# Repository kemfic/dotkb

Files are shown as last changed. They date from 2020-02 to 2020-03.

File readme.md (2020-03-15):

dotkb
---

keyboards, nothing too special. the **micro** is the only one i made so far

the micro
---
<p float='left'>
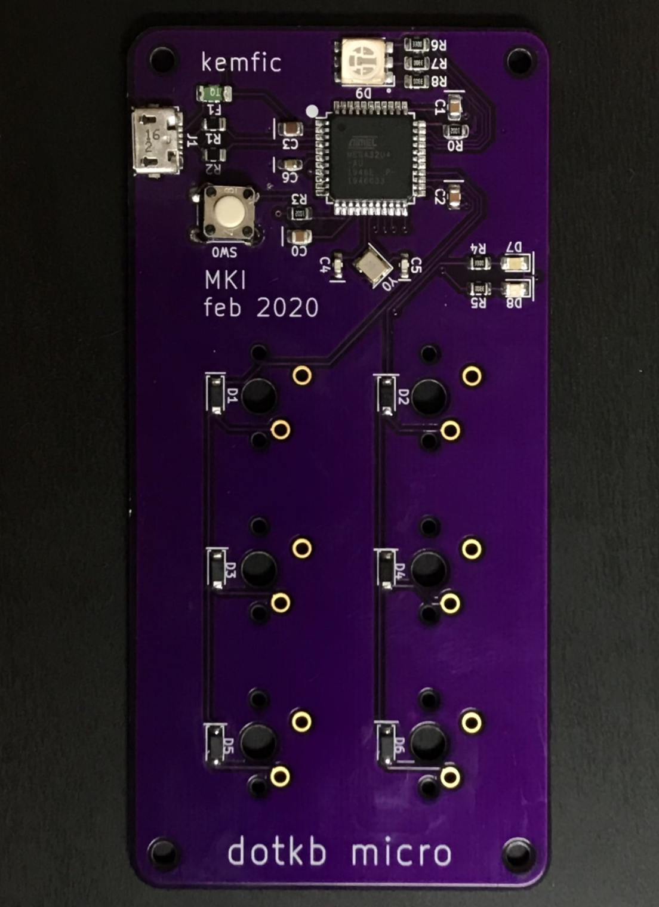
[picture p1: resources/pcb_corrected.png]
    
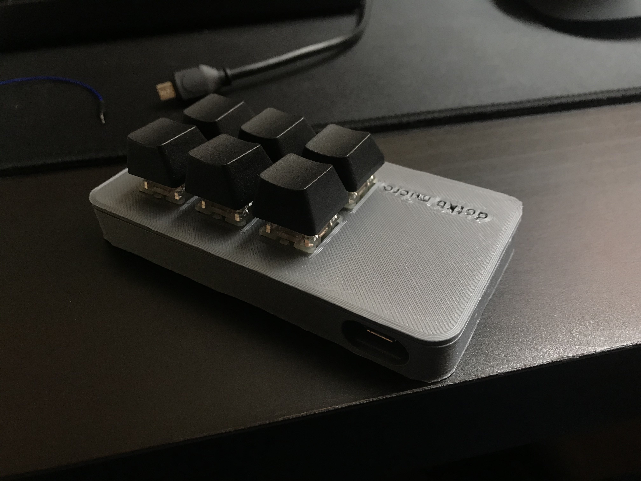
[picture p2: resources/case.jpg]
    
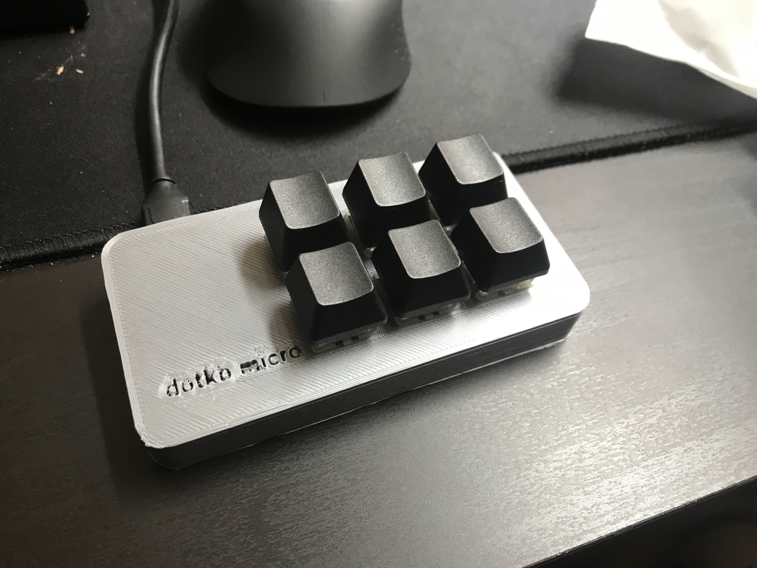
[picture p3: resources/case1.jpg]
    
</p>

features
---
 - MEAT CHECK

LICENSE
---
MIT licensed. don't sue me

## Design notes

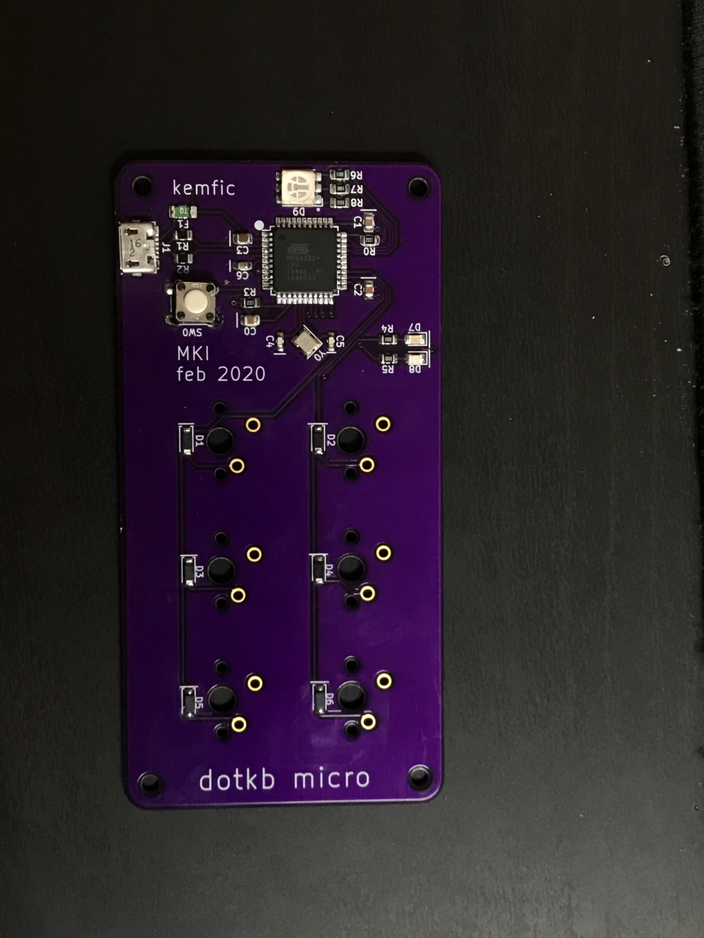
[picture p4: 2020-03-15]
resources/pcb.jpg

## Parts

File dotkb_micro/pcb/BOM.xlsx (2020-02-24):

Item | Footprint | Value | Qty | Unit Price | Total Price | Source | Part No. | Notes
Atmega32u4 | TQFP |  | 1 | 4 | 4 | Mouser | 556-ATMEGA32U4-AU
SMD Capacitor | 0805 / 2012 | 0.1uF | 3 | 0.24 | 0.72 | Mouser | 80-C0805C104K9RAUTO
SMD Capacitor | 0805 / 2012 | 10uF | 1 | 0.82 | 0.82 | Mouser | 80-C0805X106K9RAUTO
SMD Capacitor | 0603 / 1608 | 22pF | 2 | 0.26 | 0.52 | Mouser | 581-06036A220JAT2A
SMD Capacitor | 0603 / 1608 | 1uF | 1 | 0.17 | 0.17 | Mouser | 581-06036D105K
SMD Diode | D-SOD-123 |  | 7 | 0.46 | 3.22 | Mouser | 755-RRD07MM4STR
SMD LED | 0805 / 2012 | Yellow | 1 | 0.28 | 0.28 | Mouser | 720-LYR976-PS-36
SMD LED | 0805 / 2012 | Green | 1 | 0.27 | 0.27 | Mouser | 720-LGR971-KN-1
SMD RGB LED | 5050-6 | RGB | 1 | 4.95 | 4.95 | Mouser | 485-619 | Adafruit
SMD Fuse | 1206 / 3216 | 5v 500mA | 1 | 0.3 | 0.3 | Mouser | 504-PTS12066V050
Molex SMD Micro-B USB Female Connector | Micro B |  | 1 | 1.05 | 1.05 | Digi-Key | WM17141CT-ND | Molex
SMD Resistor | 0805 / 2012 | 22 Ohm | 2 | 0.25 | 0.5 | Mouser | 71-RCS080522R0FKEA
SMD Resistor | 0805 / 2012 | 10k | 2 | 0.1 | 0.2 | Mouser | 71-CRCW080510K0FKEAC
SMD Resistor | 0805 / 2012 | 330 Ohm | 5 | 0.1 | 0.5 | Mouser | 71-CRCW0805330RFKEAC
Pushbutton Switch | THT |  | 1 | 0.26 | 0.26 | Mouser | 653-B3F-1000 | Omron-B3F-10xx
SMD Crystal Oscillator | 3.2x2.5mm | 16MHz | 1 | 0.88 | 0.88 | Mouser | 815-ABM8AIG16-4T
Cherry MX Silent Red PCB Switch | PCB THT | Silent Red | 6 | 1.35 | 8.1 | Mouser | 540-MX3A-L1NA
 |  |  |  | Total: | 26.74

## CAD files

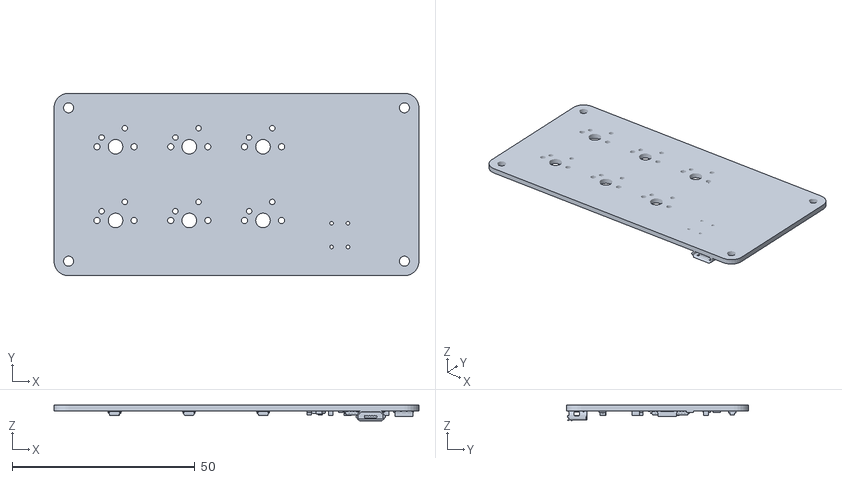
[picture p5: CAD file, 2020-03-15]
dotkb_micro/pcb/test2.stl
100.0 x 50.0 x 4.30

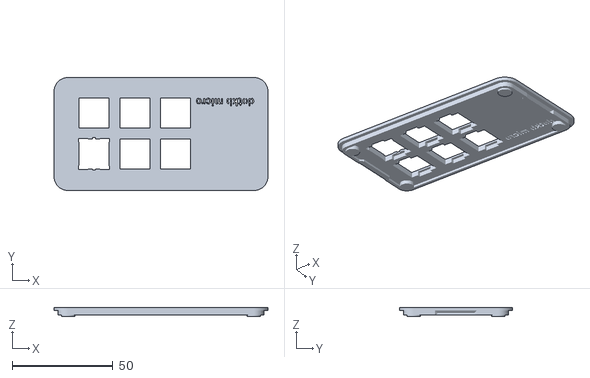
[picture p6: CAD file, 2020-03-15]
dotkb_micro/stls/Lid.stl
106.0 x 56.0 x 4.60

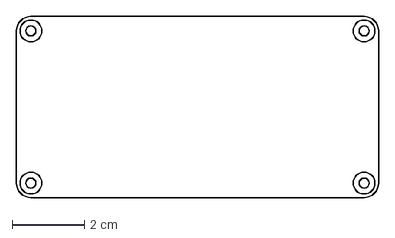
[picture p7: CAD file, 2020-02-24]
dotkb_micro/pcb/dotkb_micro.dxf
10.00 x 5.00 cm

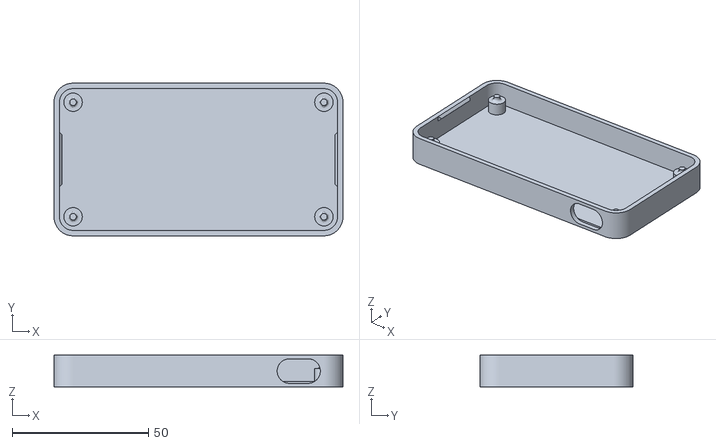
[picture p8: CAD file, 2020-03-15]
dotkb_micro/stls/Case.stl
106.0 x 56.0 x 11.6

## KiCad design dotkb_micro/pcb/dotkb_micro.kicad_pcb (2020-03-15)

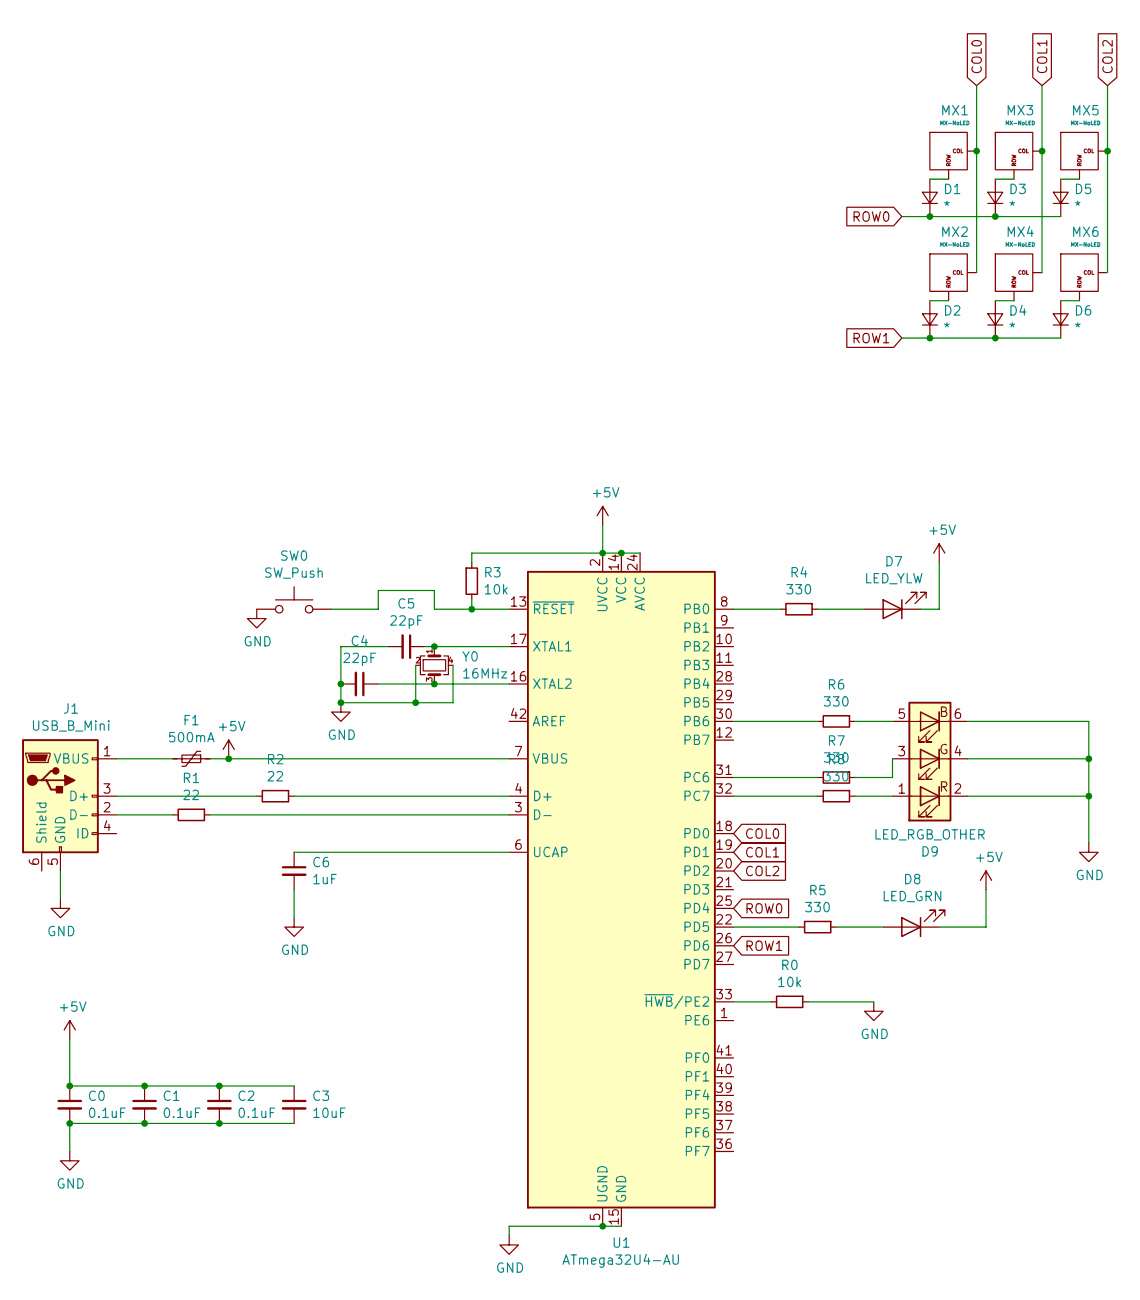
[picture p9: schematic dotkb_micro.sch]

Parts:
C0, C1, C2: 0.1uF; C_0805_2012Metric
C3: 10uF; C_0805_2012Metric
C4, C5: 22pF; C_0603_1608Metric_Pad1.05x0.95mm_HandSolder
C6: 1uF; C_0603_1608Metric_Pad1.05x0.95mm_HandSolder; Tolerance +/- 10%
D1, D2, D3, D4, D5, D6: *; D_SOD-123
D7: LED_YLW; LED_0805_2012Metric_Pad1.15x1.40mm_HandSolder
D8: LED_GRN; LED_0805_2012Metric_Pad1.15x1.40mm_HandSolder
D9: LED_RGB_OTHER; LED_RGB_5050-6-135
F1: 500mA; Fuse_1206_3216Metric
J1: USB_B_Mini; USB_Micro-B_Molex_47346-0001
MX1, MX2, MX3, MX4, MX5, MX6: MX-NoLED; SW_Cherry_MX_1.00u_PCB
R0, R3: 10k; R_0805_2012Metric
R1, R2: 22; R_0805_2012Metric
R4, R5, R6, R7, R8: 330; R_0805_2012Metric
SW0: SW_Push; SW_TH_Tactile_Omron_B3F-10xx
U1: ATmega32U4-AU; TQFP-44_10x10mm_P0.8mm
Y0: 16MHz; Crystal_SMD_3225-4Pin_3.2x2.5mm

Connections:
+5V: C0.1, C1.1, C2.1, C3.1, D7.1 (K), D8.1 (K), F1.1, R3.1, U1.2 (UVCC), U1.7 (VBUS), U1.14 (VCC), U1.24 (AVCC), U1.34 (VCC), U1.44 (AVCC)
COL0: MX1.1 (COL), MX2.1 (COL), U1.18 (PD0)
COL1: MX3.1 (COL), MX4.1 (COL), U1.19 (PD1)
COL2: MX5.1 (COL), MX6.1 (COL), U1.20 (PD2)
GND: C0.2, C1.2, C2.2, C3.2, C4.2, C5.2, C6.2, D9.2 (RK), D9.4 (GK), D9.6 (BK), J1.5 (GND), R0.1, SW0.1, U1.5 (UGND), U1.15 (GND), U1.23 (GND), U1.35 (GND), U1.43 (GND), Y0.2, Y0.4
unnamed: C4.1, U1.16 (XTAL2), Y0.3
unnamed: C5.1, U1.17 (XTAL1), Y0.1
unnamed: C6.1, U1.6 (UCAP)
unnamed: D1.2 (A), MX1.2 (ROW)
unnamed: D2.2 (A), MX2.2 (ROW)
unnamed: D3.2 (A), MX3.2 (ROW)
unnamed: D4.2 (A), MX4.2 (ROW)
unnamed: D5.2 (A), MX5.2 (ROW)
unnamed: D6.2 (A), MX6.2 (ROW)
unnamed: D7.2 (A), R4.1
unnamed: D8.2 (A), R5.1
unnamed: D9.1 (RA), R8.1
unnamed: D9.3 (GA), R7.1
unnamed: D9.5 (BA), R6.1
unnamed: F1.2, J1.1 (VBUS)
unnamed: J1.2 (D-), R1.2
unnamed: J1.3 (D+), R2.2
unnamed: R0.2, U1.33 (~HWB~/PE2)
unnamed: R1.1, U1.3 (D-)
unnamed: R2.1, U1.4 (D+)
unnamed: R3.2, SW0.2, U1.13 (~RESET)
unnamed: R4.2, U1.8 (PB0)
unnamed: R5.2, U1.22 (PD5)
unnamed: R6.2, U1.30 (PB6)
unnamed: R7.2, U1.31 (PC6)
unnamed: R8.2, U1.32 (PC7)
ROW0: D1.1 (K), D3.1 (K), D5.1 (K), U1.25 (PD4)
ROW1: D2.1 (K), D4.1 (K), D6.1 (K), U1.26 (PD6)

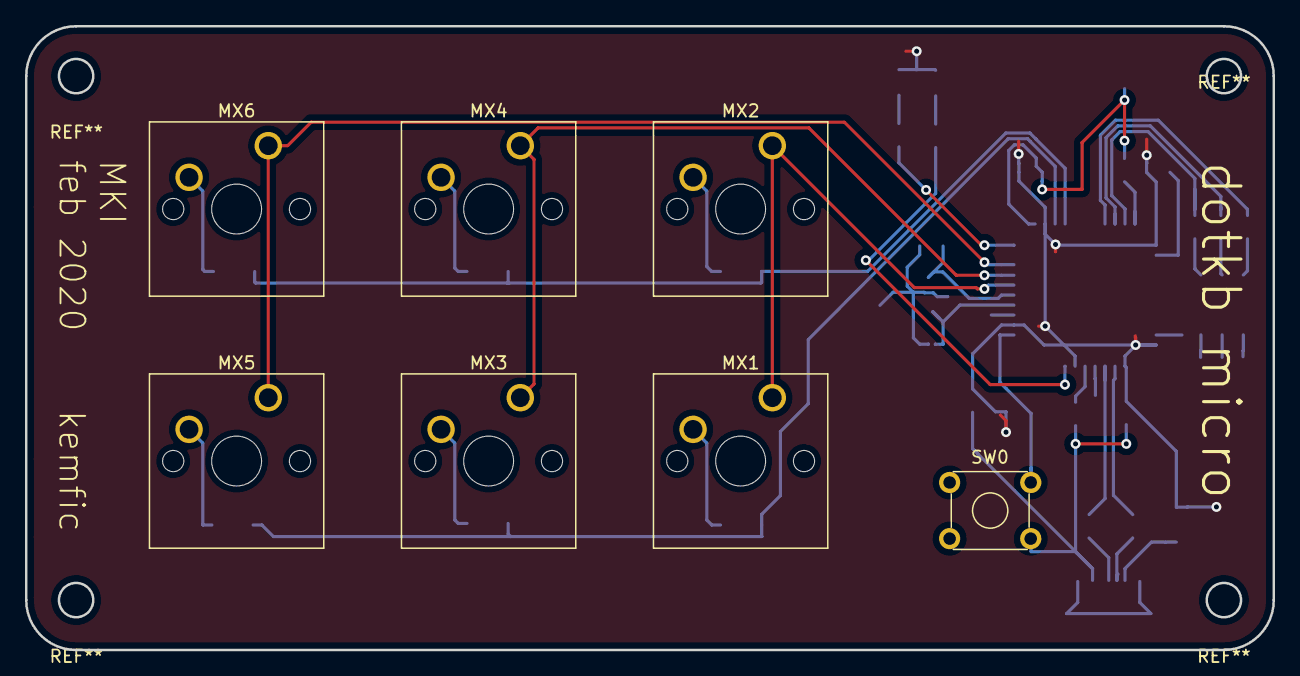
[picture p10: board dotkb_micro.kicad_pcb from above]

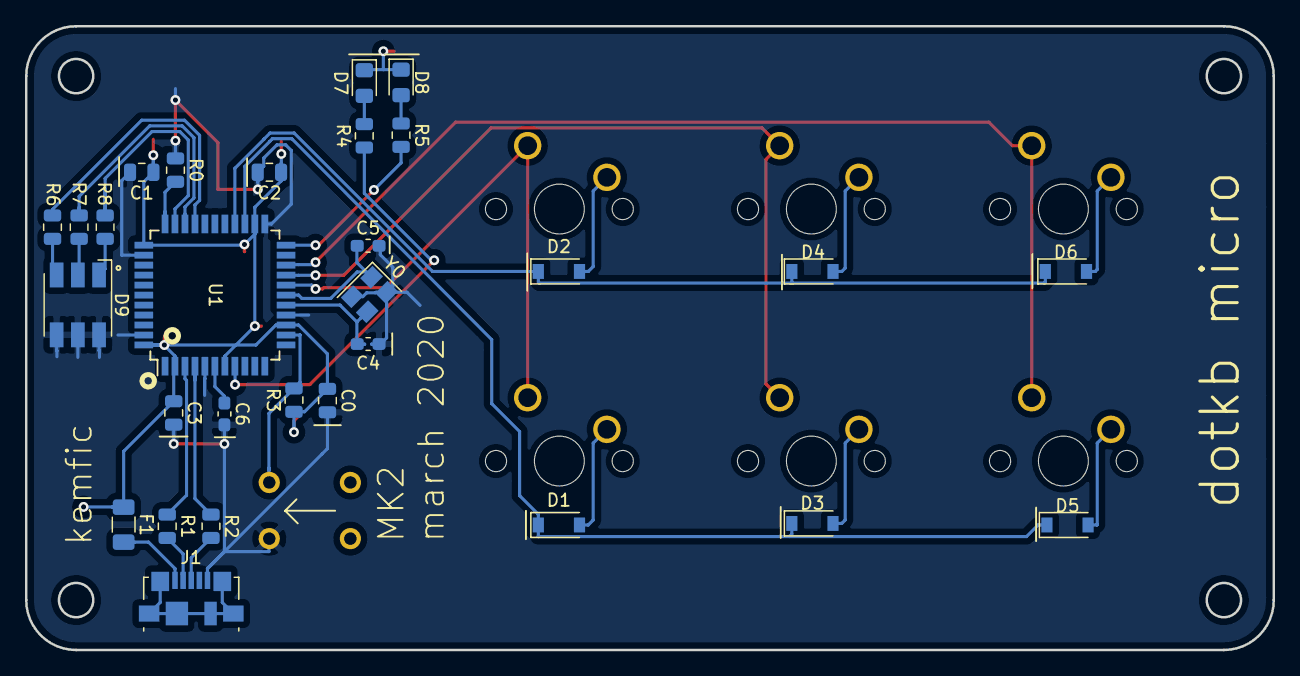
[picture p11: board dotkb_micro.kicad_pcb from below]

Board: 2 copper layers, 100.0 x 50.0 mm, 36 parts (29 on the bottom side), 33 nets.

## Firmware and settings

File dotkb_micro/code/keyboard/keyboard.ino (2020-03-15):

#include <Keyboard.h>


byte rows[] = {3,2,0}; // add row pins here
byte cols[] = {4,12};  // col pins here

const int rowCount = sizeof(rows)/sizeof(rows[0]);
const int colCount = sizeof(cols)/sizeof(cols[0]);

byte keys[colCount][rowCount];

// add keymap here
static const String keymap[colCount][rowCount] = {
    {"MEAT ", "CHECK  ", "MEAT_ "},
    {"CHEQUE ", "MiiT_ ", "CZECH"}
  };

void setup() {
  Serial.begin(115200);

  for(int i=0; i < rowCount; i++){
    pinMode(rows[i], INPUT);  
  }

  
  for(int i=0; i < colCount; i++){
    pinMode(cols[i], INPUT_PULLUP);  
  }
}

void loop() {
  //Keyboard.print("yeet \n");
  for(int i=0; i < colCount; i++){
    byte curCol = cols[i];
    pinMode(curCol, OUTPUT);
    digitalWrite(curCol, LOW);

    for(int j=0; j < rowCount; j++){
      byte curRow = rows[j];
      pinMode(curRow, INPUT_PULLUP);
      keys[i][j] = digitalRead(curRow);
      pinMode(curRow, INPUT);
    }
  pinMode(curCol, INPUT);
  }
  
  Serial.println("Matrix: ");
  for(int i=0; i < colCount; i++){
    for(int j=0; j<rowCount; j++){
      if(!keys[i][j] == true){
      Keyboard.print(keymap[i][j]);
      }
      Serial.print(keys[i][j]);
      Serial.print(F(", "));
      }
    Serial.print("\n");
  }
  delay(100);
}

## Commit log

2020-02-24 [micro] added schematic
    [dotkb_micro-B_Cu.gbr, dotkb_micro-B_Mask.gbr, dotkb_micro-B_Paste.gbr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]
2020-02-24 added micro BOM
    [BOM.xlsx]
2020-03-15 [dotkb micro] added MK2 and code
    [BOM.xlsx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]
